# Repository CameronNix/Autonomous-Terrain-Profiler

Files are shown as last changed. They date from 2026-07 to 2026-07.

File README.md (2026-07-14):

## Autonomous Terrain Profiler

Servo-mounted ultrasonic obstacle-detection system on a custom 2-layer PCB. Sweeps a 180 degree arc with an HC-SR04, flags close objects with a buzzer + LEDs.

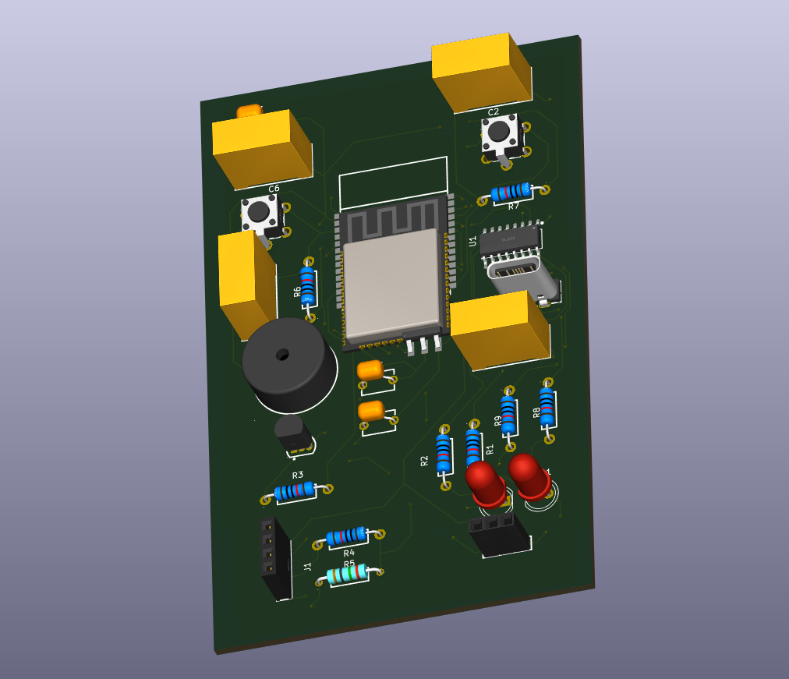
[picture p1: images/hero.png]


## Overview

**MCU:** ESP32-WROOM-32D (bare module, custom board — not a dev board)
**Sensor:** HC-SR04 ultrasonic, mounted on a servo for continuous bidirectional 180 degree sweep
**Alerts:** Transistor-switched (PN2222A) LEDs and passive buzzer, threshold-based proximity warnings
**PCB:** Custom 2-layer board designed from schematic to layout in KiCad

## Hardware

- **ESP32-WROOM-32D** — Bare module, GPIO-safe pin allocation (avoided strapping pins 0/2/5/12/15 and flash pins 6–11)
- **CH340C** — USB-UART bridge for programming, manual boot/reset via EN/GPIO0 buttons
- **AMS1117-3.3** — Voltage regulator, SOT-223, 10µF in/out caps
- **USB-C connector** — SHOU HAN TYPE-C 14-pin THT, 5.1kΩ CC1/CC2 pull-downs
- **HC-SR04** — Echo line level-shifted 5V→3.3V via 1kΩ/2kΩ voltage divider
- **Servo** — PWM control, GPIO12
- **PN2222A (x2)** — NPN low-side switches for buzzer (GPIO27) and LEDs (GPIO21/22)

All footprints sourced from LCSC part numbers and pulled into KiCad via the easyeda2kicad CLI tool for exact manufacturer-match footprints.

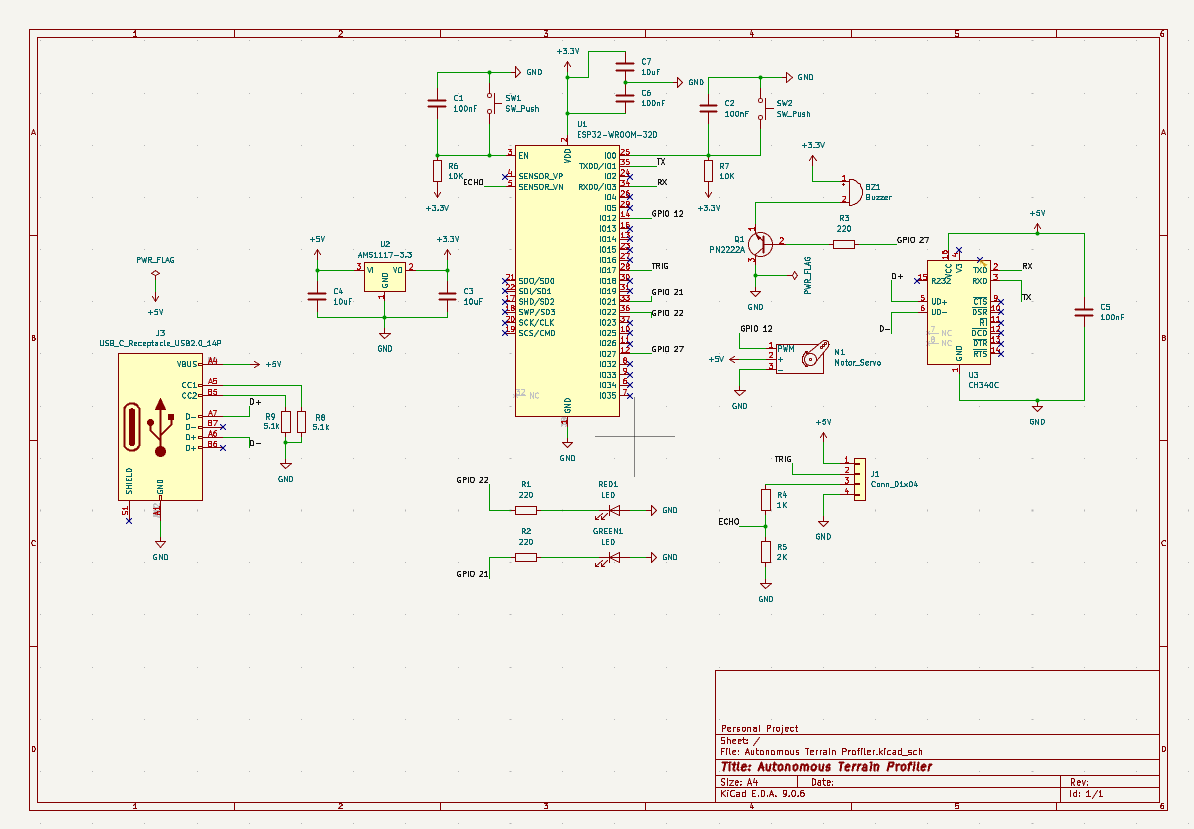
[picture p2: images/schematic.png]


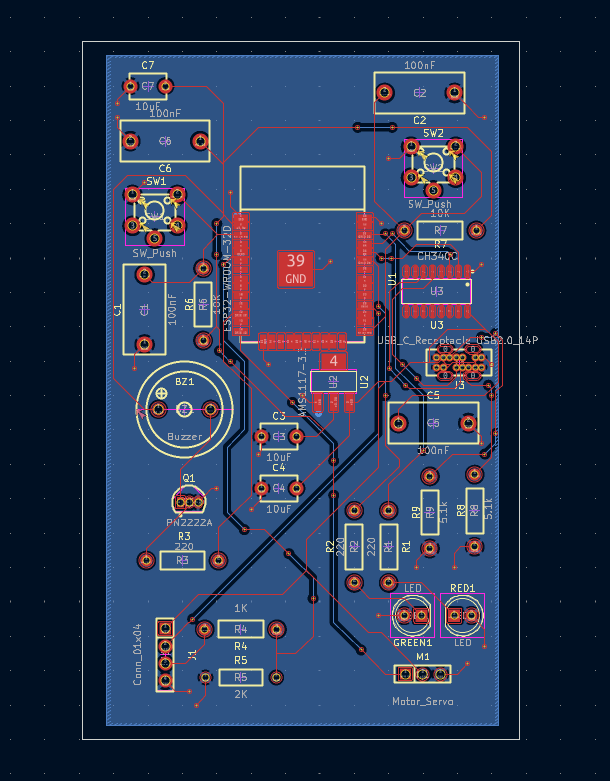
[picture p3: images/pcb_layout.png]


## Firmware

Written in C++ (Arduino framework). Core logic:

ESP32Servo for sweep positioning
HCSR04_ESP for ultrasonic timing/distance
Threshold-based alert logic (buzzer/LED) tied to sweep angle and distance

See firmware/terrain_profiler.ino.

Sweep demo

## Hardware Design Files

Complete KiCad schematic and PCB layout in hardware/. The board was fully designed and verified for manufacturability (footprints checked, DRC clean) but not fabricated, the project's firmware and sweep logic were validated on a breadboard prototype instead.

## Author

Cameron Nix — Electrical and Computer Engineering, Oregon State University

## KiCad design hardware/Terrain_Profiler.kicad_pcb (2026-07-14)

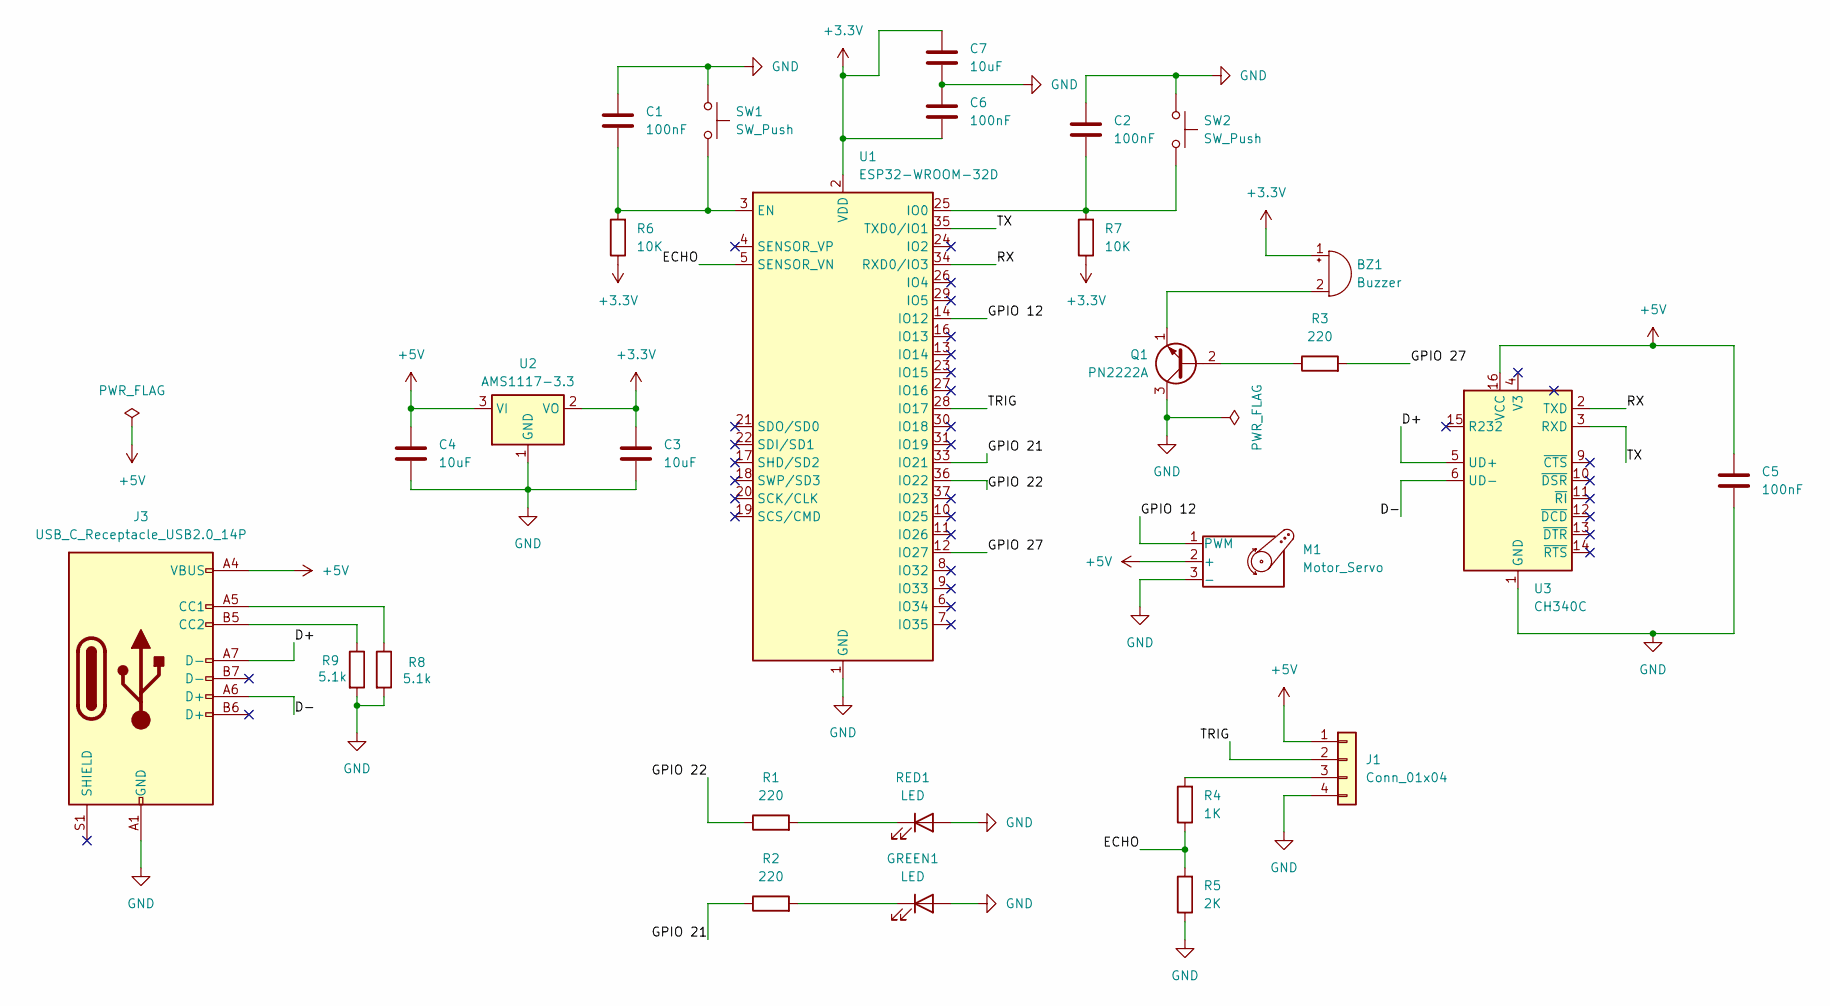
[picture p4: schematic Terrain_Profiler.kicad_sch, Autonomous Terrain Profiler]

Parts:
BZ1: Buzzer; BUZ-TH_BD14.1-P7.62-D1.0-FD
C1, C2, C5, C6: 100nF; CAP-TH_L13.0-W6.0-P10.00-D1.0
C3, C4, C7: 10uF; CAP-TH_L5.5-W3.8-P5.08-D0.5
GREEN1: LED; LED_D5.0mm
J1: Conn_01x04; HDR-TH_4P-P2.54-V-F
J3: USB_C_Receptacle_USB2.0_14P; USB-C-TH_SHOUHAN_TYPE-C-14PLC-H10.0
M1: Motor_Servo; HDR-TH_3P-P2.54-V-F
Q1: PN2222A; TO-92-3_L4.8-W3.7-P1.27-L
R1, R2, R3: 220; RES-TH_BD2.5-L6.5-P10.50-D0.6
R4: 1K; RES-TH_BD2.5-L6.5-P10.50-D0.6
R5: 2K; RES-TH_BD2.4-L6.3-P10.30-D0.6
R6, R7: 10K; RES-TH_BD2.5-L6.5-P10.50-D0.6
R8, R9: 5.1k; RES-TH_BD2.5-L6.5-P10.50-D0.6
RED1: LED; LED_D5.0mm
SW1, SW2: SW_Push; SW-TH_5P-L6.0-W6.0-P4.50-LS6.5
U1: ESP32-WROOM-32D; WIFIM-SMD_39P-L25.5-W18.0-P1.27-BL
U2: AMS1117-3.3; SOT-223-3_L6.5-W3.4-P2.30-LS7.0-BR
U3: CH340C; SOP-16_L10.0-W3.9-P1.27-LS6.0-BL

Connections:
+3.3V: BZ1.1 (+), C3.2, C6.1, C7.2, R6.1, R7.1, U1.2 (VDD), U2.2 (VO)
+5V: C4.2, C5.1, J1.1, J3.A4 (VBUS), J3.A9 (VBUS), J3.B4 (VBUS), J3.B9 (VBUS), M1.2 (+), U2.3 (VI), U3.16 (VCC)
/D+: J3.A7 (D-), U3.5 (UD+)
/D-: J3.A6 (D+), U3.6 (UD-)
/ECHO: R4.1, R5.2, U1.5 (SENSOR_VN)
/GPIO 12: M1.1 (PWM), U1.14 (IO12)
/GPIO 21: R2.1, U1.33 (IO21)
/GPIO 22: R1.1, U1.36 (IO22)
/GPIO 27: R3.2, U1.12 (IO27)
/RX: U1.34 (RXD0/IO3), U3.2 (TXD)
/TRIG: J1.2, U1.28 (IO17)
/TX: U1.35 (TXD0/IO1), U3.3 (RXD)
GND: C1.1, C2.1, C3.1, C4.1, C5.2, C6.2, C7.1, GREEN1.2 (A), J1.4, J3.A1 (GND), J3.A12 (GND), J3.B1 (GND), J3.B12 (GND), M1.3 (-), Q1.3 (C), R5.1, R8.2, R9.2, RED1.2 (A), SW1.1, SW2.1, U1.1 (GND), U1.15 (GND), U1.38 (GND), U1.39 (GND), U2.1 (GND), U3.1 (GND)
unnamed: BZ1.2 (-), Q1.1 (E)
unnamed: GREEN1.1 (K), R2.2
unnamed: J1.3, R4.2
unnamed: J3.A5 (CC1), R8.1
unnamed: J3.B5 (CC2), R9.1
unnamed: Q1.2 (B), R3.1
unnamed: R1.2, RED1.1 (K)
unnamed: C1.2, R6.2, SW1.2, U1.3 (EN)
unnamed: C2.2, R7.2, SW2.2, U1.25 (IO0)

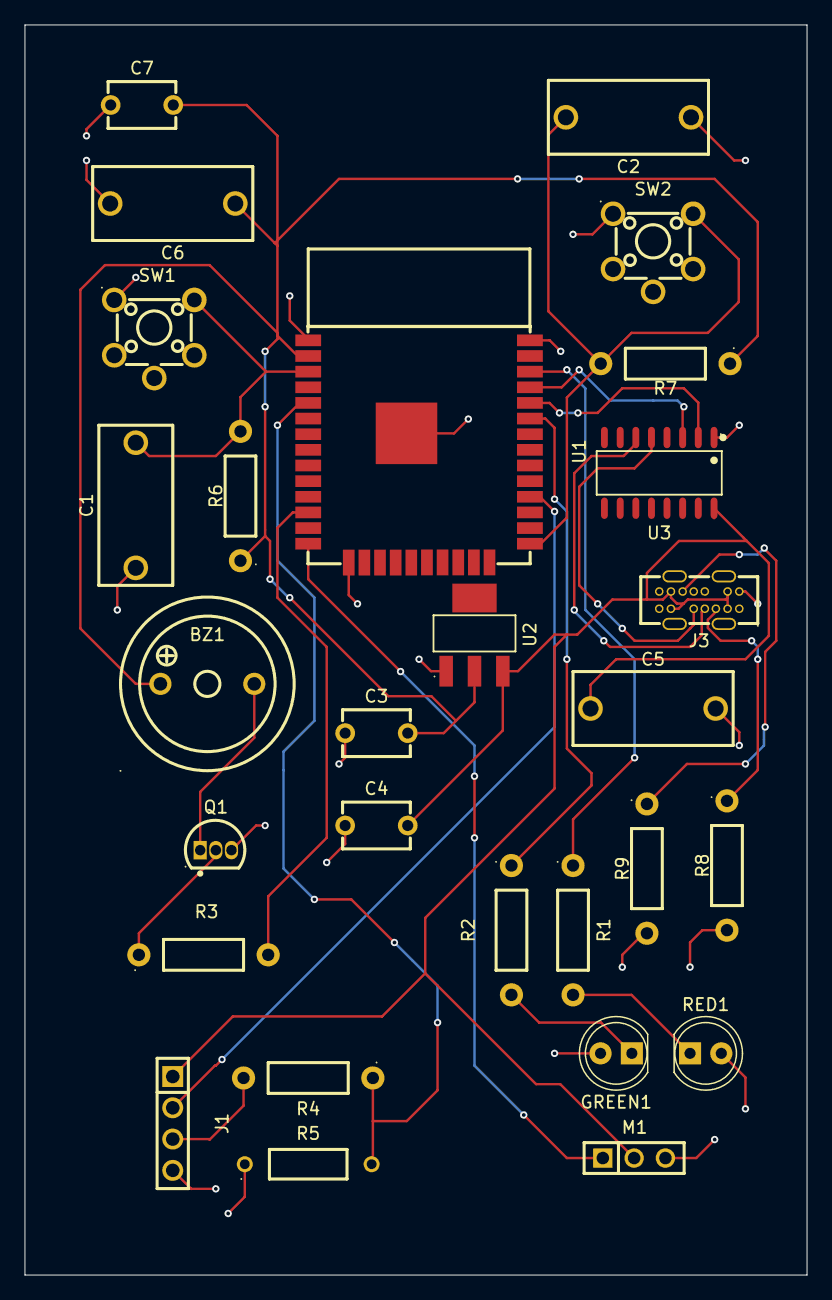
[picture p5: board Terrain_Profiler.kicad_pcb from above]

Board: 2 copper layers, 63.5 x 101.5 mm, 28 parts (0 on the bottom side), 22 nets.

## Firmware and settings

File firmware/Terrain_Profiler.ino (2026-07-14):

#include <ESP32Servo.h>
#include <HCSR04_ESP.h>
#include <Adafruit_GFX.h>
#include <Adafruit_SH110X.h>

#define servoPin 12
#define echoPin 39
#define trigPin 17
#define R_LED 22
#define G_LED 21
#define BUZZER 27


Servo MyServo;
HCSR04Sensor sensor(17, 39);

void setup() {
  Serial.begin(115200);
  sensor.begin();
  pinMode(17, OUTPUT);
  pinMode(39, INPUT);
  pinMode(21, OUTPUT);
  pinMode(22, OUTPUT);
  pinMode(27, OUTPUT);
  MyServo.attach(servoPin);
  MyServo.write(0);
  digitalWrite(G_LED, HIGH);
  digitalWrite(R_LED, LOW);
  digitalWrite(BUZZER, LOW);
}

void loop() {
   int i = 0;
   for(i = 0; i <= 180; i++) {
    MyServo.write(i);
    float distance = sensor.readDistanceCm();
    if(distance <= 20) {
      digitalWrite(R_LED, HIGH);
      digitalWrite(G_LED, LOW);
      digitalWrite(BUZZER, HIGH);
    } else {
      digitalWrite(R_LED, LOW);
      digitalWrite(G_LED, HIGH);
      digitalWrite(BUZZER, LOW);
    }
    
   }
   for(i = 180; i >= 0; i--) {
    MyServo.write(i);
    float distance = sensor.readDistanceCm();
    if(distance <= 20) {
      digitalWrite(R_LED, HIGH);
      digitalWrite(G_LED, LOW);
      digitalWrite(BUZZER, HIGH);
    } else {
      digitalWrite(R_LED, LOW);
      digitalWrite(G_LED, HIGH);
      digitalWrite(BUZZER, LOW);
    }
    
  }
}
